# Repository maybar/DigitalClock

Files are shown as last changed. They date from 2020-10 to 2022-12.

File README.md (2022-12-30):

# DigitalClock
## Wall Digital Clock 

Conexiones
|Pin	|Dir	|Función 	|  
|---|-----|---|
| D0 	| ->  | BUZZER			|  
| D1 	| ->  | SCL CLOCK		|
| D2 	| <-> | SDA CLOCK		|
| D3 	|		|	|
| D4 	| ->  | LED DATA		|
| D5	|	|	|
| D6	|	|	|
| D7 	| <-  | PIR			|
| D8	|	|	|
| A0 	| <-  | LIGHT SENSOR	|

Basado en 
https://github.com/leonvandenbeukel/7-Segment-Digital-Clock-V2

Añadir al gestor URLs de tarjetas de arduino:
https://arduino.esp8266.com/stable/package_esp8266com_index.json

Instalar plugin para subir data a la memoria Flash, y ponerla en la siguinete ruta:
C:\Users\Miguel\Documents\Arduino\Workspace\tools\ESP8266FS\tool\esp8266fs.jar

Consumo
Sin Leds: 80mA  400mW
Brillo
255         300mA
128         200mA
67          155mA
50			130mA
34          119mA
21          111mA
15          110mA
10          110mA

float batteryLevel = map(analogRead(33), 0.0f, 4095.0f, 0, 100);

Clonar la librería para Arduino
git clone https://github.com/esp8266/Arduino.git esp8266/Arduino

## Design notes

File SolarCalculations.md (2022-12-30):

# Cálculos de energía

## Cálculo del panel
Energia en San Sebastian
Diarios: 3.2 KWh/m2
Anuales: 1100 KWh/m2

1100KWh/8760h = 126W/m2

Eficiencia del panel solar = 15%
-> 19W/m2

Eficiencia de la carga de batería: 33%
-> 6W/m2
0.6mW/cm2

Calculo del tamaño del panel solar
0,33W/6W/m2 = 0,055m2  = 50cm2
aprox 7cm x 7cm

## ---
Panel solar:
5v x 160mA  = 800mW
90 x 70 = 6300mm2 = 63cm2
Consumo:
ESP8266 3.3 x 0.1A = 0,33W

## Batería
Noche: 7horasx0.08A =0,56Ah

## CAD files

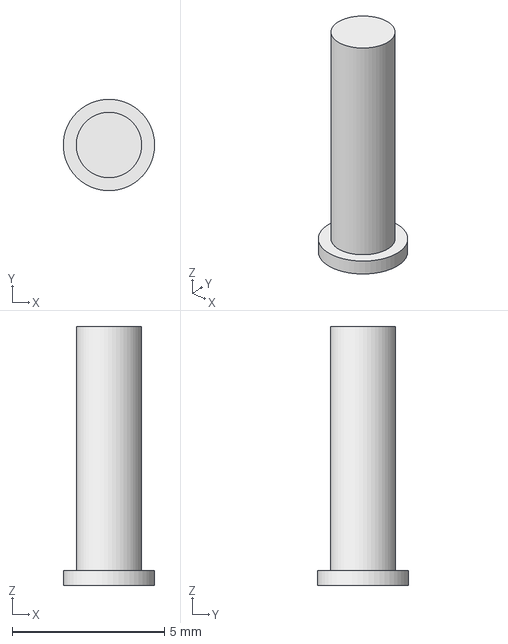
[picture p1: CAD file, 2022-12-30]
Modelo3D/Auxiliares.FCStd
3.00 x 3.00 x 8.50 mm

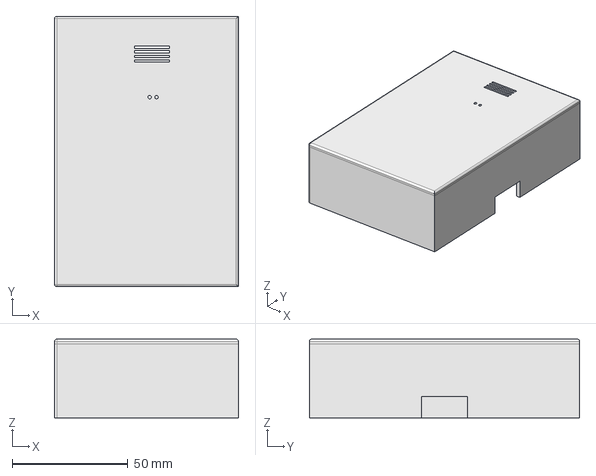
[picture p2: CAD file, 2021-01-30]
Modelo3D/ElectricBox.FCStd
79.5 x 116.8 x 34.0 mm

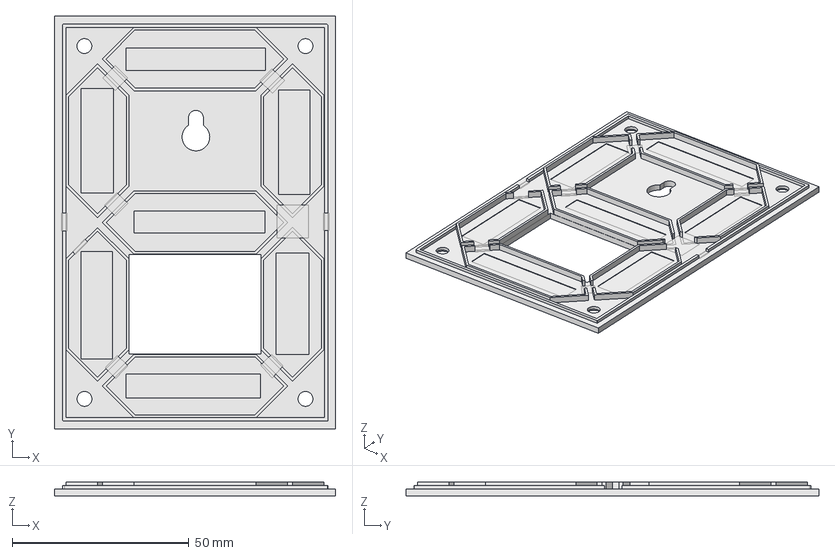
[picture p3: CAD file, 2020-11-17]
Modelo3D/DigitalClock.FCStd
79.5 x 116.8 x 4.00 mm

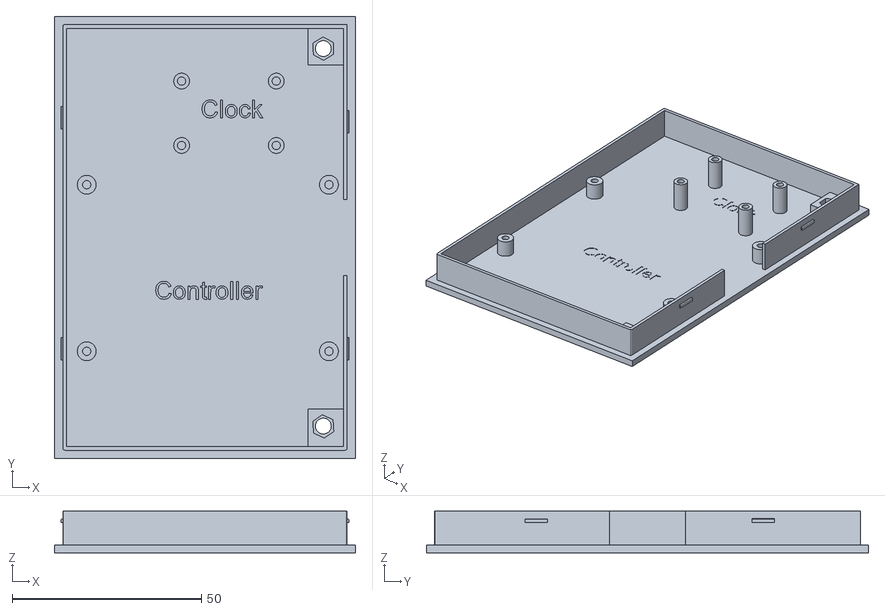
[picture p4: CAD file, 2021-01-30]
Modelo3D/STL/BottonElectricBox.stl
79.5 x 116.8 x 11.0

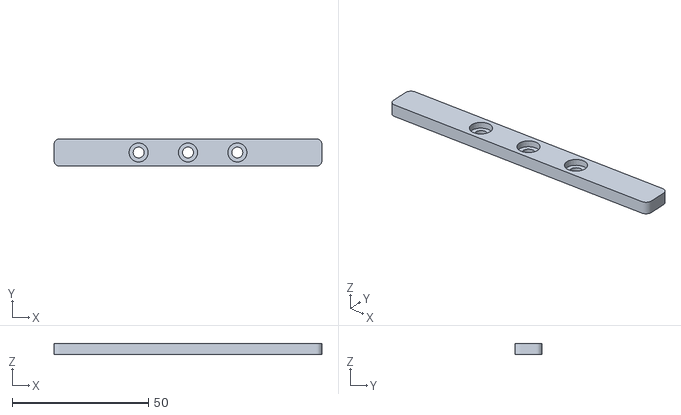
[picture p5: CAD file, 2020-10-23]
Modelo3D/STL/AttachLarge.stl
98.2 x 10.0 x 4.00

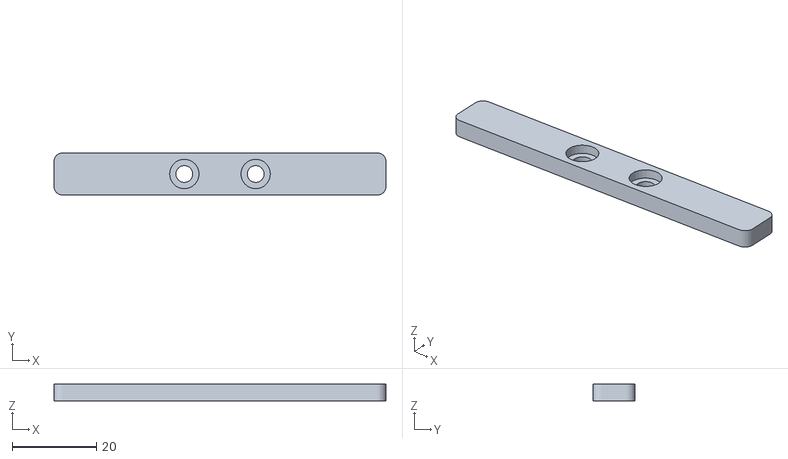
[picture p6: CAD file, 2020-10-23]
Modelo3D/STL/AttachSmall.stl
79.0 x 10.0 x 4.00

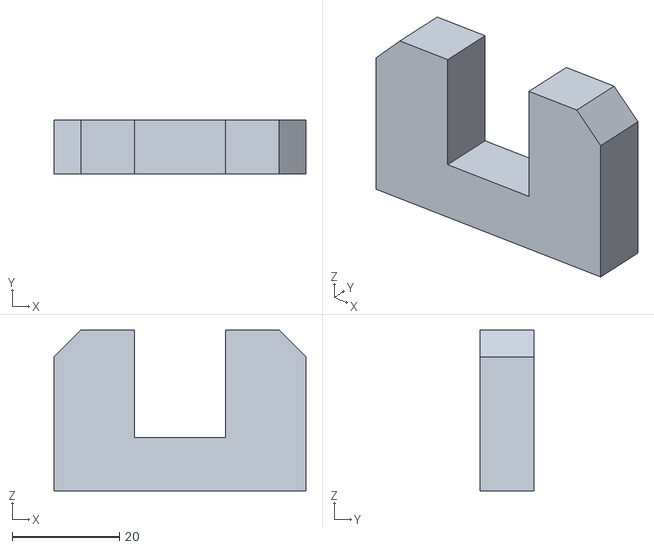
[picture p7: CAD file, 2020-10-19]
Modelo3D/STL/Stand.stl
47.0 x 10.0 x 30.0

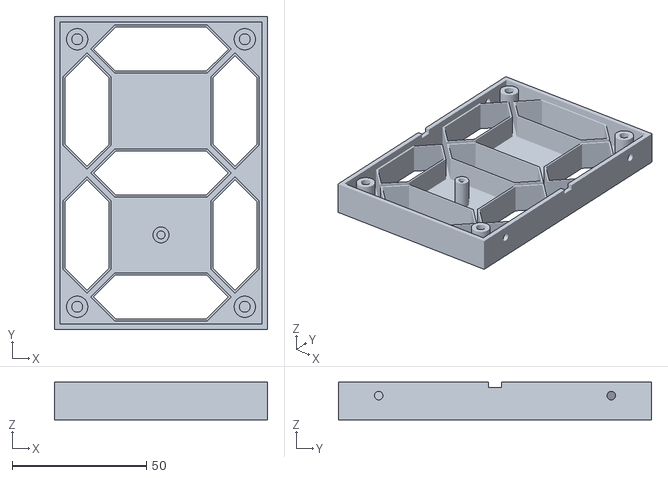
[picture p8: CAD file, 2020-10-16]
Modelo3D/STL/Top.stl
79.5 x 116.8 x 14.0

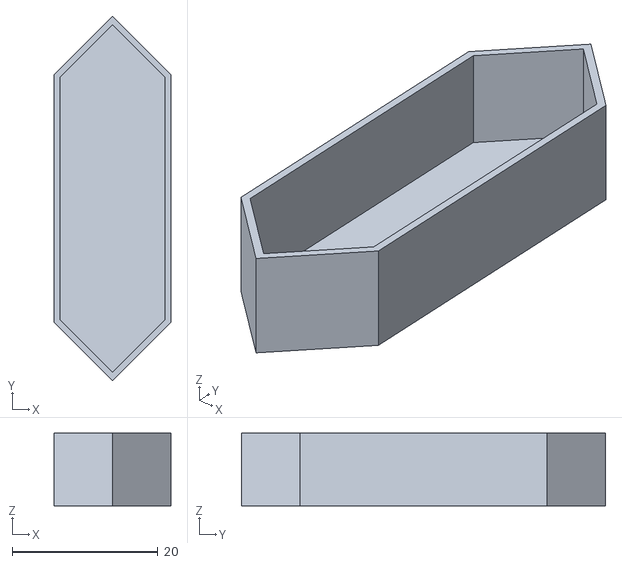
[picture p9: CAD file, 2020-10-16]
Modelo3D/STL/SegmentHor.stl
16.0 x 49.9 x 10.0

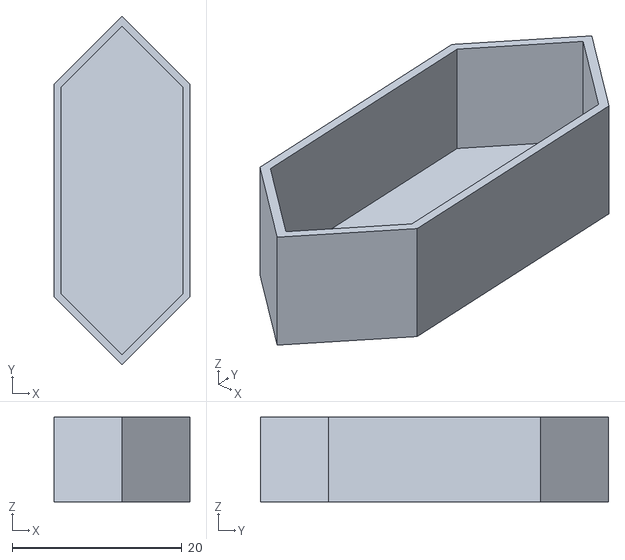
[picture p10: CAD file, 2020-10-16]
Modelo3D/STL/SegmentVert.stl
16.0 x 41.0 x 10.00

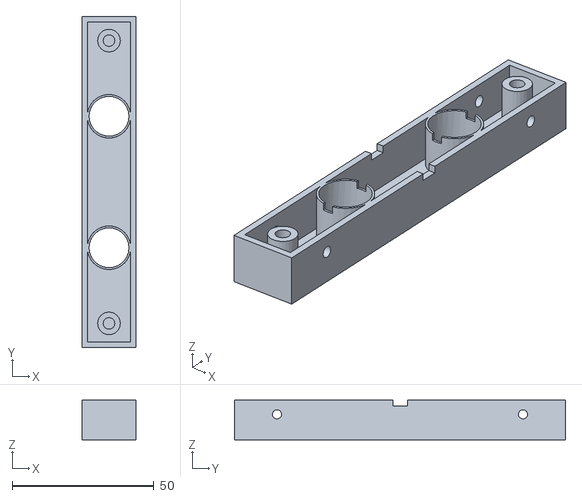
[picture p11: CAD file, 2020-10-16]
Modelo3D/STL/MiddleTop.stl
19.2 x 116.8 x 14.0

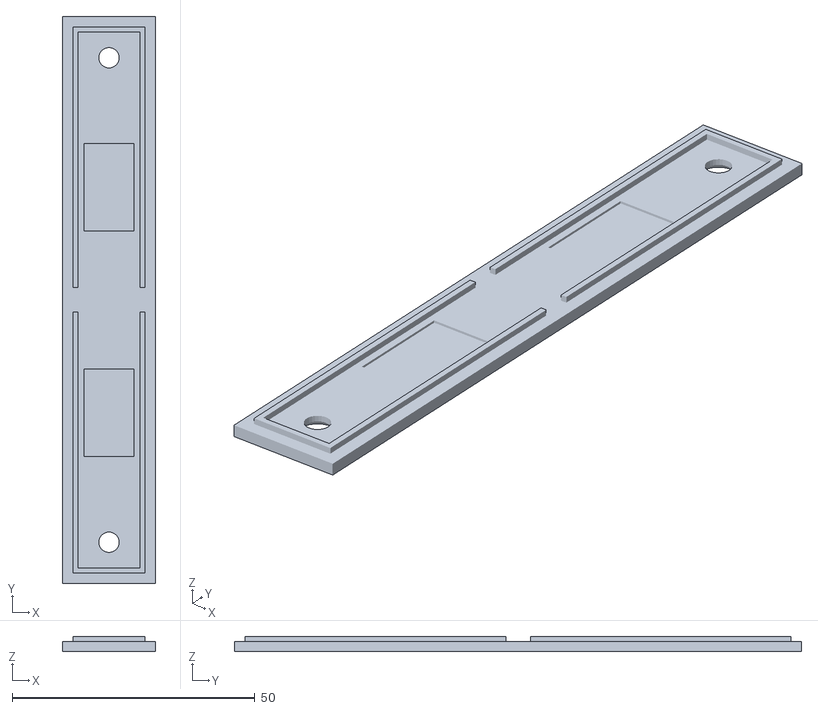
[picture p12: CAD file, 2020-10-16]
Modelo3D/STL/MiddleBottom.stl
19.2 x 116.8 x 3.00

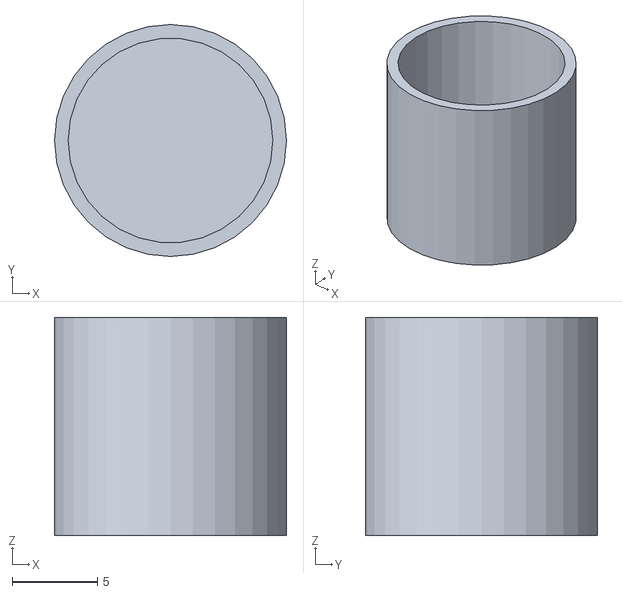
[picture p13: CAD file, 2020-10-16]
Modelo3D/STL/Dot.stl
13.6 x 13.6 x 12.8

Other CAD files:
Modelo3D/STL/Pin.stl
Modelo3D/STL/TopElectricBox.stl
Modelo3D/STL/Bottom.stl

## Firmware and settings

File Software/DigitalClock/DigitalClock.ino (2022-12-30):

#include <FastLED.h>                          // Include FastLED by Danuel Garcia (Lib Manager)
#include <Wire.h>
#include <RtcDS3231.h>                        // Include RTC library by Makuna: https://github.com/Makuna/Rtc
#define FASTLED_INTERNAL
#include <FastLED.h>
#include "server_wifi.h"
/* ------------------------
 *  Install Board: esp8266 by ESP8266 Community
 PLACA: WEMOS MINI D1
 LOLIN(WEMOS) D1 R2 & Mini
 Upload speed:921600
 80 MHz - 4MB FS:2MB OTA:1019KB

 -------------------------*/
#define countof(a) (sizeof(a) / sizeof(a[0]))
#define NUM_LEDS 30                           // Total of 30 LED's     
#define MILLI_AMPS 500                        // 500mA 
#define COUNTDOWN_OUTPUT D5                   // OUTPUT_PIN (Buzzer)
//D1 -> SCL CLOCK
//D2 -> SDA CLOCK
#define DATA_PIN D4                           // OUTPUT_PIN - Change this if you are using another type of ESP board than a WeMos D1 Mini
#define LDR_SENSOR_PIN A0                     // INPUT PIN

RtcDS3231<TwoWire> Rtc(Wire);
CRGB LEDs[NUM_LEDS];
ServerWifi server_wifi;

// Settings
unsigned long _ul_last_trigger = 0;
bool buzzer_on = false;
unsigned long prevTime = 0;
byte r_val = 0;
byte g_val = 255;
byte b_val = 0;
bool dotsOn = true;
byte brightness = 255;
float temperatureCorrection = -3.0;
byte temperatureSymbol = 12;                  // 12=Celcius, 13=Fahrenheit check 'numbers'
byte clockMode = 0;                           // Clock modes: 0=Clock, 1=Countdown, 2=Temperature, 3=Scoreboard
unsigned long countdownMilliSeconds;
unsigned long endCountDownMillis;
byte hourFormat = 24;                         // Change this to 12 if you want default 12 hours format instead of 24               
CRGB countdownColor = CRGB::Green;
byte scoreboardLeft = 0;
byte scoreboardRight = 0;
CRGB scoreboardColorLeft = CRGB::Green;
CRGB scoreboardColorRight = CRGB::Red;
CRGB alternateColor = CRGB::Black; 
long numbers[] = {
  0b0111111,  // [0] 0
  0b0001100,  // [1] 1
  0b1011011,  // [2] 2
  0b1011110,  // [3] 3
  0b1101100,  // [4] 4
  0b1110110,  // [5] 5
  0b1110111,  // [6] 6
  0b0011100,  // [7] 7
  0b1111111,  // [8] 8
  0b1111110,  // [9] 9
  0b0000000,  // [10] off
  0b1111000,  // [11] degrees symbol
  0b0110011,  // [12] C(elsius)
  0b1011100,  // [13] F(ahrenheit)
};

uint8_t hora=0;
uint8_t minuto=0;
uint8_t segundo = 0;

void updateClock();
void updateCountdown();
void updateTemperature();
void updateScoreboard();
void displayDots(CRGB color);
void wifi_client();
void light_sensor();

void setup() {
  pinMode(COUNTDOWN_OUTPUT, OUTPUT);
  Serial.begin(115200); 
  delay(200);

  // RTC DS3231 Setup
  Rtc.Begin();    
  RtcDateTime compiled = RtcDateTime(__DATE__, __TIME__);

  if (!Rtc.IsDateTimeValid()) {
      if (Rtc.LastError() != 0) {
          // we have a communications error see https://www.arduino.cc/en/Reference/WireEndTransmission for what the number means
          Serial.print("RTC communications error = ");
          Serial.println(Rtc.LastError());
      } else {
          // Common Causes:
          //    1) first time you ran and the device wasn't running yet
          //    2) the battery on the device is low or even missing
          Serial.println("RTC lost confidence in the DateTime!");
          // following line sets the RTC to the date & time this sketch was compiled
          // it will also reset the valid flag internally unless the Rtc device is
          // having an issue
          Rtc.SetDateTime(compiled);
      }
  }
  Serial.println("RTC started");
  
  FastLED.addLeds<WS2812B, DATA_PIN, GRB>(LEDs, NUM_LEDS);  
  FastLED.setDither(false);
  FastLED.setCorrection(TypicalLEDStrip);
  FastLED.setMaxPowerInVoltsAndMilliamps(5, MILLI_AMPS);
  fill_solid(LEDs, NUM_LEDS, CRGB::Black);
  FastLED.show();
  Serial.println("FastlED started!");

  server_wifi.setup(&LEDs[0]);
  Serial.println("WIFI started!");
  FastLED.clear();

  //Serial.setDebugOutput(true);

  digitalWrite(COUNTDOWN_OUTPUT, HIGH);
  delay(3000);
  digitalWrite(COUNTDOWN_OUTPUT, LOW);
 
}

void loop(){
  // WIFI
  wifi_client();
  
  //CLOCK
  unsigned long currentMillis = millis();  
  if (currentMillis - prevTime >= 1000) {
    prevTime = currentMillis;

    if (clockMode == 0) {
      updateClock();
    } else if (clockMode == 1) {
      updateCountdown();
    } else if (clockMode == 2) {
      updateTemperature();      
    } else if (clockMode == 3) {
      updateScoreboard();            
    }

    // Light sensor
    light_sensor();
    
    FastLED.setBrightness(brightness);
    FastLED.show();
  }   

  // BUZZER
  if (buzzer_on)
  {
    if ((currentMillis - _ul_last_trigger) > (2000))
    {
      if (digitalRead(COUNTDOWN_OUTPUT))
        digitalWrite(COUNTDOWN_OUTPUT, LOW);
      else
        digitalWrite(COUNTDOWN_OUTPUT, HIGH);
      _ul_last_trigger = millis();
    }
  }
  else
  {
    digitalWrite(COUNTDOWN_OUTPUT, LOW);
  }
}

void light_sensor()
{
  int sensorValue = analogRead(LDR_SENSOR_PIN);
  brightness = map(sensorValue, 0, 1023, 10, 150);
}

bool if_day()
{
  if ((hora > 6) && (hora < 18))
    return true;
  else
    return false;
}


void displayNumber(byte number, byte segment, CRGB color) {
 /*
 * 
    _4         __            __        __  
  _5   _3    __   __   14  __  __   __    __
    _6         __            __        __  
  _0   _2    _7   __   15  16  __   23    __
    _1         __            __        __   

 */
 
  // segment from left to right: 3, 2, 1, 0
  byte startindex = 0;
  switch (segment) {
    case 0:
      startindex = 23;
      break;
    case 1:
      startindex = 16;
      break;
    case 2:
      startindex = 7;
      break;
    case 3:
      startindex = 0;
      break;    
  }

  for (byte i=0; i<7; i++){
    yield();
    LEDs[i + startindex] = ((numbers[number] & 1 << i) == 1 << i) ? color : alternateColor;
  } 
}

void allBlank() {
  for (int i=0; i<NUM_LEDS; i++) {
    LEDs[i] = CRGB::Black;
  }
  FastLED.show();
}

void updateClock() {  
  RtcDateTime now = Rtc.GetDateTime();
  printDateTime(now);    

  int hour = now.Hour();
  int mins = now.Minute();
  int secs = now.Second();

  hora = hour;
  minuto = mins;
  segundo = secs;

  if (hourFormat == 12 && hour > 12)
    hour = hour - 12;
  
  byte h1 = hour / 10;
  byte h2 = hour % 10;
  byte m1 = mins / 10;
  byte m2 = mins % 10;  
  byte s1 = secs / 10;
  byte s2 = secs % 10;
  
  CRGB color = CRGB(r_val, g_val, b_val);

  if (h1 > 0)
    displayNumber(h1,3,color);
  else 
    displayNumber(10,3,color);  // Blank
    
  displayNumber(h2,2,color);
  displayNumber(m1,1,color);
  displayNumber(m2,0,color); 

  displayDots(color);  
}

void updateCountdown() {

  if (countdownMilliSeconds == 0 && endCountDownMillis == 0) 
    return;
    
  unsigned long restMillis = endCountDownMillis - millis();
  unsigned long hours   = ((restMillis / 1000) / 60) / 60;
  unsigned long minutes = (restMillis / 1000) / 60;
  unsigned long seconds = restMillis / 1000;
  int remSeconds = seconds - (minutes * 60);
  int remMinutes = minutes - (hours * 60); 
  
  Serial.print(restMillis);
  Serial.print(" ");
  Serial.print(hours);
  Serial.print(" ");
  Serial.print(minutes);
  Serial.print(" ");
  Serial.print(seconds);
  Serial.print(" | ");
  Serial.print(remMinutes);
  Serial.print(" ");
  Serial.println(remSeconds);

  byte h1 = hours / 10;
  byte h2 = hours % 10;
  byte m1 = remMinutes / 10;
  byte m2 = remMinutes % 10;  
  byte s1 = remSeconds / 10;
  byte s2 = remSeconds % 10;

  CRGB color = countdownColor;
  if (restMillis <= 60000) {
    color = CRGB::Red;
  }

  if (hours > 0) {
    // hh:mm
    displayNumber(h1,3,color); 
    displayNumber(h2,2,color);
    displayNumber(m1,1,color);
    displayNumber(m2,0,color);  
  } else {
    // mm:ss   
    displayNumber(m1,3,color);
    displayNumber(m2,2,color);
    displayNumber(s1,1,color);
    displayNumber(s2,0,color);  
  }

  displayDots(color);  

  if (hours <= 0 && remMinutes <= 0 && remSeconds <= 0) {
    Serial.println("Countdown timer ended.");
    //endCountdown();
    countdownMilliSeconds = 0;
    endCountDownMillis = 0;
    buzzer_on = true;
    _ul_last_trigger = millis();
    return;
  }  
}

void endCountdown() {
  allBlank();
  for (int i=0; i<NUM_LEDS; i++) {
    if (i>0)
      LEDs[i-1] = CRGB::Black;
    
    LEDs[i] = CRGB::Red;
    FastLED.show();
    delay(25);
  }  
}

void displayDots(CRGB color) {
  if (dotsOn) {
    LEDs[14] = color;
    LEDs[15] = color;
  } else {
    LEDs[14] = CRGB::Black;
    LEDs[15] = CRGB::Black;
  }

  dotsOn = !dotsOn;  
}

void hideDots() {
  LEDs[14] = CRGB::Black;
  LEDs[15] = CRGB::Black;
}

void updateTemperature() {
  RtcTemperature temp = Rtc.GetTemperature();
  float ftemp = temp.AsFloatDegC();
  float ctemp = ftemp + temperatureCorrection;
  Serial.print("Sensor temp: ");
  Serial.print(ftemp);
  Serial.print(" Corrected: ");
  Serial.println(ctemp);

  if (temperatureSymbol == 13)
    ctemp = (ctemp * 1.8000) + 32;

  byte t1 = int(ctemp) / 10;
  byte t2 = int(ctemp) % 10;
  CRGB color = CRGB(r_val, g_val, b_val);
  displayNumber(t1,3,color);
  displayNumber(t2,2,color);
  displayNumber(11,1,color);
  displayNumber(temperatureSymbol,0,color);
  hideDots();
}

void updateScoreboard() {
  byte sl1 = scoreboardLeft / 10;
  byte sl2 = scoreboardLeft % 10;
  byte sr1 = scoreboardRight / 10;
  byte sr2 = scoreboardRight % 10;

  displayNumber(sl1,3,scoreboardColorLeft);
  displayNumber(sl2,2,scoreboardColorLeft);
  displayNumber(sr1,1,scoreboardColorRight);
  displayNumber(sr2,0,scoreboardColorRight);
  hideDots();
}

void printDateTime(const RtcDateTime& dt)
{
    char datestring[20];

    snprintf_P(datestring, 
            countof(datestring),
            PSTR("%02u/%02u/%04u %02u:%02u:%02u"),
            dt.Month(),
            dt.Day(),
            dt.Year(),
            dt.Hour(),
            dt.Minute(),
            dt.Second() );
    Serial.println(datestring);
}

void wifi_client()
{
  SClockData s_data_clock;
  server_wifi.process(s_data_clock);
  r_val = s_data_clock.r_val;
  g_val = s_data_clock.g_val;
  b_val = s_data_clock.b_val;
  brightness = s_data_clock.brightness;
  hourFormat = s_data_clock.hourFormat;

  if (server_wifi.is_new_timedate())
  {
    char d[12];
    char t[9];
    s_data_clock.date.toCharArray(d, 12);
    s_data_clock.time.toCharArray(t, 9);
    RtcDateTime compiled = RtcDateTime(d, t);
    Rtc.SetDateTime(compiled);   
    clockMode = 0; 
    //hora = compiled.Hour();
    //minuto = compiled.Minute();
    //segundo = compiled.Second();
    buzzer_on = false;   
  }

  if (server_wifi.is_new_countdown())
  {
    buzzer_on =false;
    countdownMilliSeconds = s_data_clock.countdownMilliSeconds;
    countdownColor = CRGB(s_data_clock.cd_r_val, s_data_clock.cd_g_val, s_data_clock.cd_b_val); 
    endCountDownMillis = millis() + countdownMilliSeconds;
    allBlank(); 
    clockMode = 1;     
  }

  if (server_wifi.is_new_temperature())
  {
    temperatureCorrection = s_data_clock.temperatureCorrection;
    temperatureSymbol = s_data_clock.temperatureSymbol;
    clockMode = 2; 
  }

  if (server_wifi.is_new_hourformat() or server_wifi.is_new_clock())
  {
    temperatureCorrection = s_data_clock.temperatureCorrection;
    temperatureSymbol = s_data_clock.temperatureSymbol;
    clockMode = 0;
    buzzer_on = false;
  }
}

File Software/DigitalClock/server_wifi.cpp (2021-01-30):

#include <ESP8266WiFi.h>
#include <ESP8266WebServer.h>
#include <ESP8266HTTPUpdateServer.h>
#define FASTLED_INTERNAL
#include <FastLED.h>
#include <FS.h>                               // Please read the instructions on http://arduino.esp8266.com/Arduino/versions/2.3.0/doc/filesystem.html#uploading-files-to-file-system
#include "server_wifi.h"

#define WIFIMODE 1                            // 0 = Only Soft Access Point, 1 = Only connect to local WiFi network with UN/PW, 2 = Both

#if defined(WIFIMODE) && (WIFIMODE == 0 || WIFIMODE == 2)
  const char* APssid = "CLOCK_AP";        
  const char* APpassword = "1234567890";  
#endif
  
#if defined(WIFIMODE) && (WIFIMODE == 1 || WIFIMODE == 2)
  #include "Credentials.h"                    // Create this file in the same directory as the .ino file and add your credentials (#define SID YOURSSID and on the second line #define PW YOURPASSWORD)
  const char *ssid = SID;
  const char *password = PW;
#endif
ESP8266WebServer server(80);
ESP8266HTTPUpdateServer httpUpdateServer;

SClockData s_clock_data;
bool update_timedate;
bool update_countdown;
bool update_temperature;
bool update_hourformat;
bool update_clock;

ServerWifi::ServerWifi()
{
  update_timedate = false;
  update_countdown = false;
  update_temperature = false;
  update_hourformat = false;
  update_clock = false;

  s_clock_data.r_val = 0;
  s_clock_data.g_val = 255;
  s_clock_data.b_val = 0;
  s_clock_data.brightness = 10;
  s_clock_data.temperatureCorrection = -3.0;
  s_clock_data.temperatureSymbol = 12;                  // 12=Celcius, 13=Fahrenheit check 'numbers'
  s_clock_data.hourFormat = 24;                         // Change this to 12 if you want default 12 hours format instead of 24  
}

void ServerWifi::setup(CRGB *LEDs)
{
    WiFi.setSleepMode(WIFI_NONE_SLEEP); 
    delay(200);

    // WiFi - AP Mode or both
#if defined(WIFIMODE) && (WIFIMODE == 0 || WIFIMODE == 2) 
  WiFi.mode(WIFI_AP_STA);
  WiFi.softAP(APssid, APpassword);    // IP is usually 192.168.4.1
  Serial.println();
  Serial.print("SoftAP IP: ");
  Serial.println(WiFi.softAPIP());
#endif

  start_wifi(LEDs);   

  httpUpdateServer.setup(&server);

  // Handlers
  //server.on("/color", HTTP_POST, prueba);
  server.on("/color", HTTP_POST, []() {    
    s_clock_data.r_val = server.arg("r").toInt();
    s_clock_data.g_val = server.arg("g").toInt();
    s_clock_data.b_val = server.arg("b").toInt();
    server.send(200, "text/json", "{\"result\":\"ok\"}");
  });

  server.on("/setdate", HTTP_POST, []() { 
    // Sample input: date = "Dec 06 2009", time = "12:34:56"
    // Jan Feb Mar Apr May Jun Jul Aug Sep Oct Nov Dec
    String datearg = server.arg("date");
    String timearg = server.arg("time");
    Serial.println(datearg);
    Serial.println(timearg);    
    server.send(200, "text/json", "{\"result\":\"ok\"}");
    s_clock_data.date = datearg;
    s_clock_data.time = timearg;
    update_timedate = true;
  });

  server.on("/brightness", HTTP_POST, []() {    
    s_clock_data.brightness = server.arg("brightness").toInt();    
    server.send(200, "text/json", "{\"result\":\"ok\"}");
    Serial.println(s_clock_data.brightness);
  });
  
  server.on("/countdown", HTTP_POST, []() {    
    s_clock_data.countdownMilliSeconds = server.arg("ms").toInt();     
    s_clock_data.cd_r_val = server.arg("r").toInt();
    s_clock_data.cd_g_val = server.arg("g").toInt();
    s_clock_data.cd_b_val = server.arg("b").toInt();
    server.send(200, "text/json", "{\"result\":\"ok\"}");
    update_countdown = true;
  });

  server.on("/temperature", HTTP_POST, []() {   
    s_clock_data.temperatureCorrection = server.arg("correction").toInt();
    s_clock_data.temperatureSymbol = server.arg("symbol").toInt();    
    server.send(200, "text/json", "{\"result\":\"ok\"}");
    update_temperature = true;
  });  

  server.on("/hourformat", HTTP_POST, []() {   
    s_clock_data.hourFormat = server.arg("hourformat").toInt();     
    server.send(200, "text/json", "{\"result\":\"ok\"}");
    update_hourformat = true;
  }); 

  server.on("/clock", HTTP_POST, []() {          
    server.send(200, "text/json", "{\"result\":\"ok\"}");
    update_clock = true;
  });  

   // Before uploading the files with the "ESP8266 Sketch Data Upload" tool, zip the files with the command "gzip -r ./data/" (on Windows I do this with a Git Bash)
  // *.gz files are automatically unpacked and served from your ESP (so you don't need to create a handler for each file).
  server.serveStatic("/", SPIFFS, "/", "max-age=86400");
  server.begin();     

  if (!SPIFFS.begin()){
    Serial.println("An Error has occurred while mounting SPIFFS");
    return;
  }
  Serial.println("SPIFFS contents:");
  Dir dir = SPIFFS.openDir("/");
  while (dir.next()) {
    String fileName = dir.fileName();
    size_t fileSize = dir.fileSize();
    Serial.printf("FS File: %s, size: %s\n", fileName.c_str(), String(fileSize).c_str());
  }
  Serial.println(); 

}

void ServerWifi::process(SClockData & data)
{
    server.handleClient();
    data =s_clock_data;
}


bool ServerWifi::is_new_timedate(void)
{
    if (update_timedate)
    {
        update_timedate = false;
        return true;
    }
    return false;
}

bool ServerWifi::is_new_countdown(void)
{
    if (update_countdown)
    {
        update_countdown = false;
        return true;
    }
    return false;
}

bool ServerWifi::is_new_temperature(void)
{
    if (update_temperature)
    {
        update_temperature = false;
        return true;
    }
    return false;
}

bool ServerWifi::is_new_hourformat(void)
{
    if (update_hourformat)
    {
        update_hourformat = false;
        return true;
    }
    return false;
}

bool ServerWifi::is_new_clock(void)
{
    if (update_clock)
    {
        update_clock = false;
        return true;
    }
    return false;
}

void ServerWifi::start_wifi(CRGB *LEDs)
{
   // WiFi - Local network Mode or both
#if defined(WIFIMODE) && (WIFIMODE == 1 || WIFIMODE == 2) 
  byte count = 0;
  WiFi.begin(ssid, password);
  while (WiFi.status() != WL_CONNECTED) {
    // Stop if cannot connect
    if (count >= 60) {
      Serial.println("Could not connect to local WiFi.");      
      return;
    }
       
    delay(500);
    Serial.print(".");
    LEDs[count] = CRGB::White;
    FastLED.show();
    count++;
  }
  Serial.print("Local IP: ");
  Serial.println(WiFi.localIP());

  IPAddress ip = WiFi.localIP();

#endif
}

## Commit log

2020-10-16 Pruebas con Nano Arduino
    [AttachLarge.stl, AttachSmall.stl, Bottom.stl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]
2020-10-18 Software para WemosD1
2020-10-19 Stand STL
    [DigitalClock.FCStd, Stand.stl]
2020-10-23 Pruebas PIR
    [AttachLarge.stl, AttachSmall.stl, DigitalClock.FCStd]
2020-11-14 Versión final sin PIR no batería.
    [DigitalClock.FCStd]
2020-11-17 Minimo brillo = 2
    [DigitalClock.FCStd]
2021-01-30 Version Definitiva Brill0: 10-150 para cubierta de papel
    [BottonElectricBox.stl, DigitalClock.fzz, ElectricBox.FCStd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]
2022-12-30 Resuelve el bloqueo del reloj
    [Auxiliares.FCStd, Pin.stl]
2026-01-23 Archivo de credenciales WiFi
